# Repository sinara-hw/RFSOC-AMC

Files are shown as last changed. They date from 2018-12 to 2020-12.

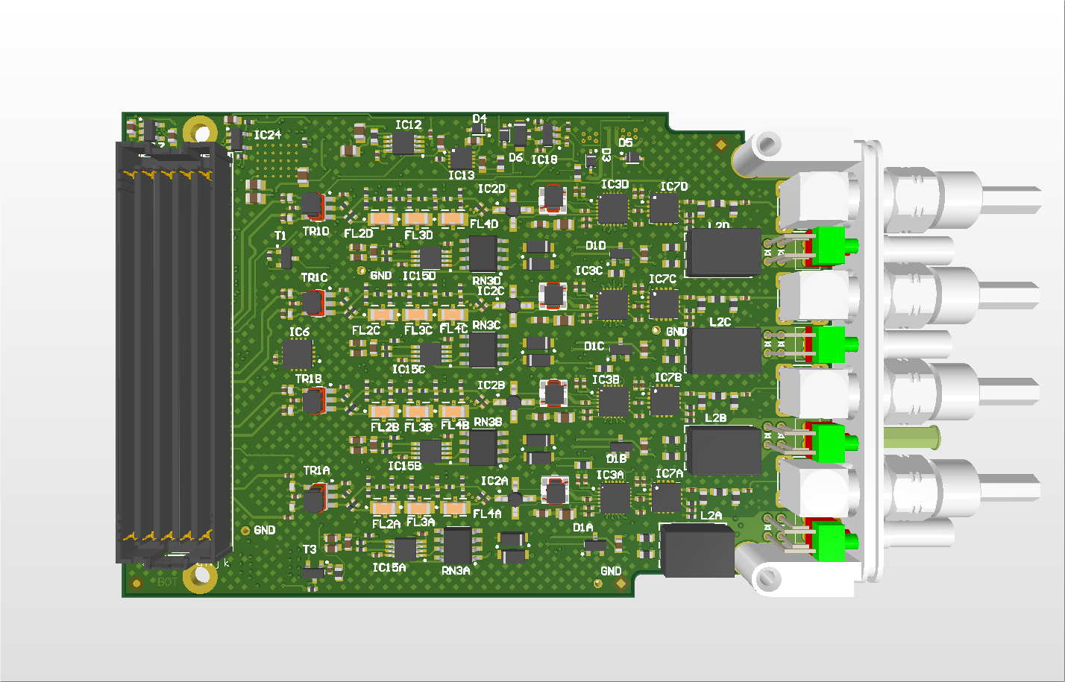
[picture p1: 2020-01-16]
DOC/mezzanine.png

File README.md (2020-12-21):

# RFSOC-AMC
AMC module with Xilinx RF-SoC and two analog front-end mezzanines for SDR and quantum applications

## Design Files

Design files (schematics, PCB layouts, BOMs) can be found at [RFSOC-AMC/Releases](https://github.com/sinara-hw/RFSOC-AMC/releases).

## Wiki

More information can be found on the [wiki](https://github.com/sinara-hw/RFSOC-AMC/wiki).

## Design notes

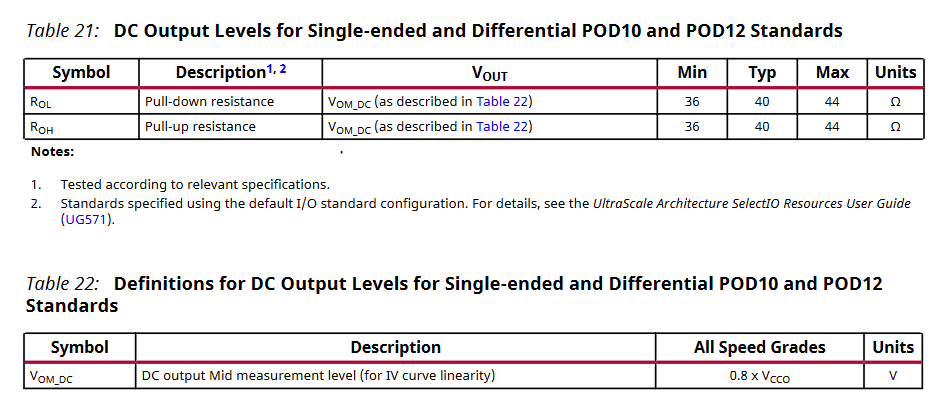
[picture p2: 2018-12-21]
POD12_o_levels.PNG

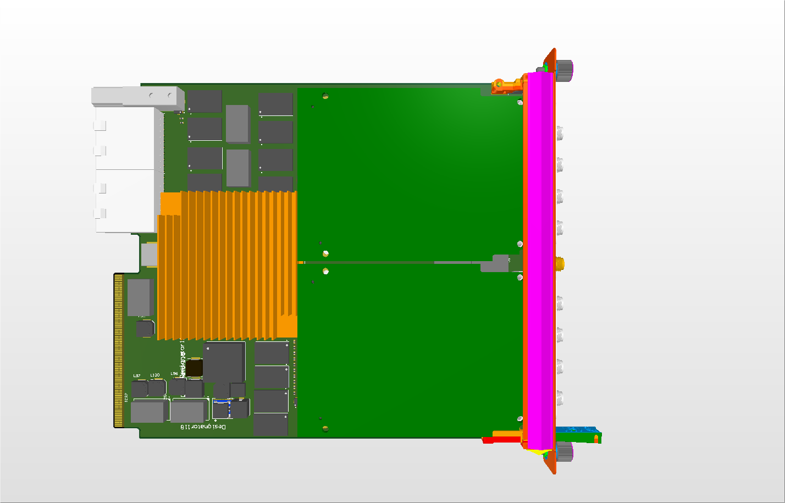
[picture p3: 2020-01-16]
DOC/top.png

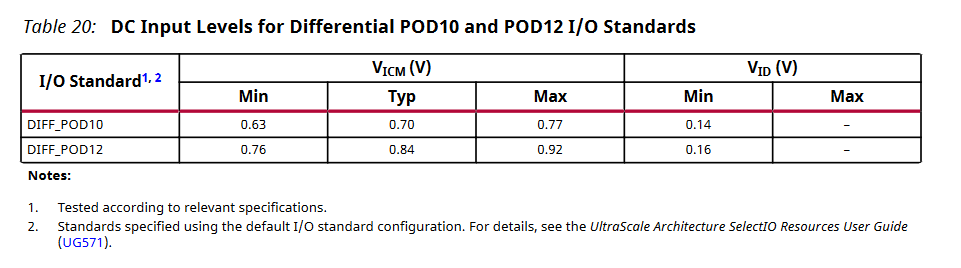
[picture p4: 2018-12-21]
POD12_i_levels.PNG

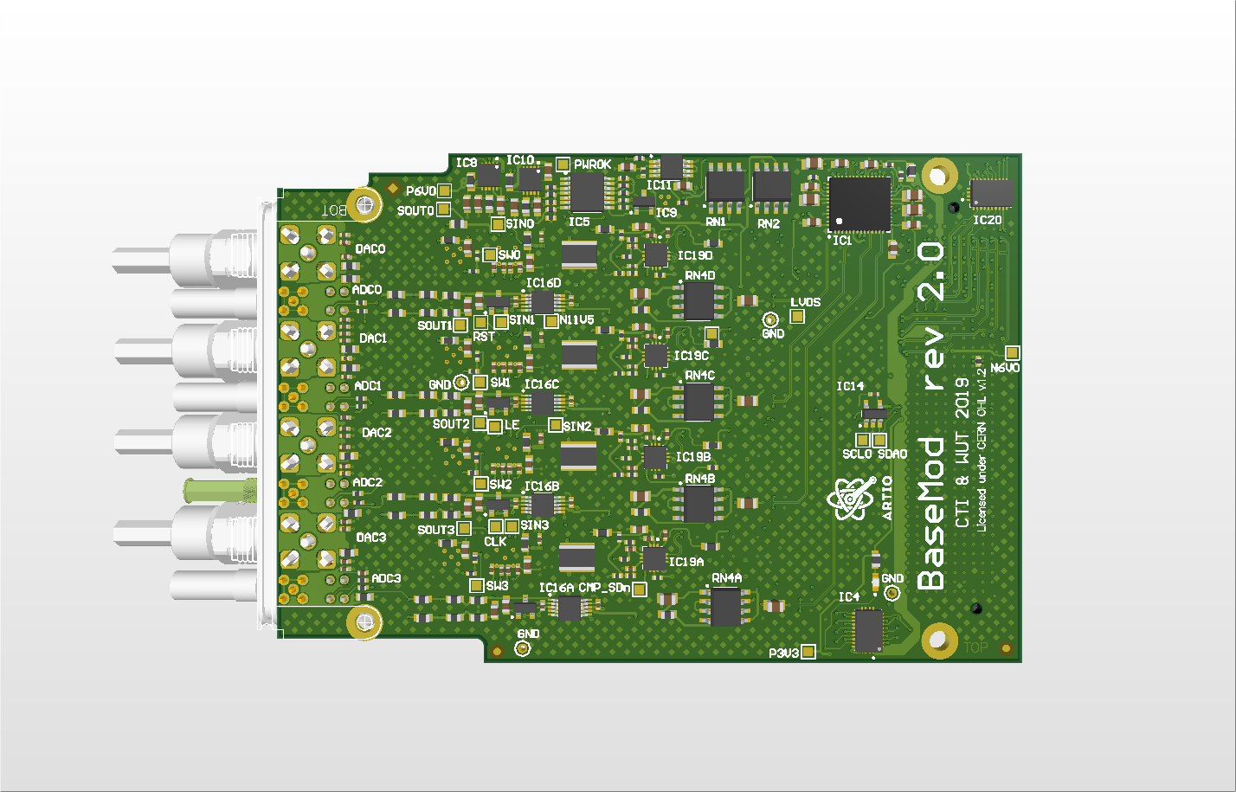
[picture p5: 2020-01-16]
DOC/mezzanine top.png

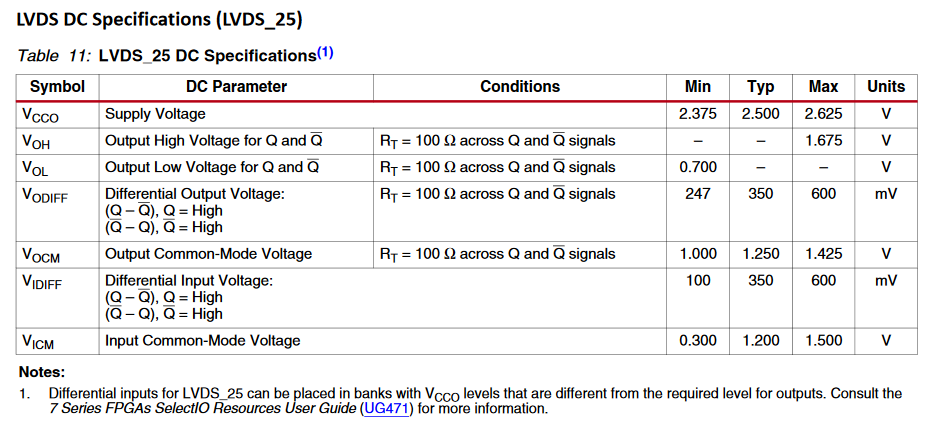
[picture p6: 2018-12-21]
LVDS_25_levels.PNG

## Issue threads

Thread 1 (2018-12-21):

[RFC] RFSoCs from Xilinx

gkasprow, 2018-12-21:
I got involved in new project at the WUT.
We will build wideband MIMO SDR. Probably on the new RFSoC that:
- are pin compatible with ZU25
- offer 8x 10G DACs and 8x 5G ADCs

You won't find any info with Mr Google. I got this news from my colleague.
For the WUT project existing 6G DAC with DUC and 4G ADC with DDC would probably be enough, but I want to play with newest SOCs.
For what applications would you use such beast? Would such upgrade for Sayma ecosystem be useful for ion trappers?
My colleagues from NBI would love to use it for superconducting qubit readout.
I still don't know what the ADC-DAC latency is. They need <1us together with demodulation and modulation algorithm. Both ADC and DAC use AXI stream.
I plan to buy ZCU111 and simply measure it.
The configuration for WUT project is minimal. I want to use 1517 package an hook up as many DDR4 channels as possible for all AWG applications.
Is there any benefit of using Sayma AMC in such configuraiton?
Initial idea is to make it as RTM and place SFP/QSFP, clock recovery, MMC, supply on AMC side.

camillehyrien, 2019-02-25:
> I saw it. But it has so many variables like inter-tile alignment and various synchronisation features.
> I will try to simulate the design with Vivado simulator where I can enter analog values and observe analog outputs.

Do you find another way to run simulation? (for example to see spectrum ? )

I have another question, do you find a way to synchronize your mesurement equipment and the ZCU111 dev board with LMK2594? Do you need to configure a MTS mode, or non-MTS mode? In which way you connected it? I tried several times but It failed.

gkasprow, 2019-02-25:
I'm still waiting for ZCU111 devkit. I didn't touch it for some time since it is a low priority.

gkasprow, 2019-09-08:
We measured the latency:
ADC - DMA - DAC. And it is roughly 160ns with interpolation and decimation and 109ns without.
Some results are [here](https://gitlab.com/wut_ise/pados/issues/8)

camillehyrien, 2019-09-09:
> We measured the latency:
> ADC - DMA - DAC. And it is roughly 160ns with interpolation and decimation and 109ns without.
> Some results are [here](https://gitlab.com/wut_ise/pados/issues/8)

Thank you for this information, I am not able to see the link : https://gitlab.com/wut_ise/pados/issues/8. May you post the result in a pdf format? Thank you

gkasprow, 2019-09-09:
This result (160 ns delay) is when using 2x interpolation and 2x decimation on DAC and ADC respectively. 4,096 GSPS.
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

109 ns is without interpolation and decimation and 4,096 GSPS, however you cannot set this configuration from GUI as GUI prevents DAC AXI stream clock from being higher than 500 MHz. I did this from PYNQ level.
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

gkasprow, 2019-09-09:
__
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

gkasprow, 2019-09-09:
The cable lengths were compensated

gkasprow, 2021-10-04:
PCB progress update
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
Mezzanine
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

dtcallcock, 2021-10-04:
FYI, there is now an open-source superconducting qubit project based on an RFSoC eval board.

[https://arxiv.org/abs/2110.00557](https://arxiv.org/abs/2110.00557)
[https://github.com/openquantumhardware/qick](https://github.com/openquantumhardware/qick)

Sandia have a similar thing aimed at ion traps too.  Not sure if that will be opened up.

[https://www.osti.gov/doecode/biblio/46631](https://www.osti.gov/doecode/biblio/46631)

gkasprow, 2021-10-04:
Yes, I know. I wrote to David already :)

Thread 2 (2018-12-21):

Design choices

gkasprow, 2018-12-21:
So far several aspects were decided:
- AMC form factor
- 2 AFE modules a'la Sayma
- RTM compatible with [RTM-SFP-QSFP](https://github.com/gkasprow/RTM_4SFP_3QSFP)
- AMC FatPipe1 support for DRTIO and PCIe
- clock racovery same as on Sayma (WR-type) + Xilinx devkit-style ADC/DAC clock generation
- 2x 64bit PL-DDR4
- 1x64bit PS-DDR4
- power supplies based on uModules like on Sayma RTM
- small FPGA for AFE control like on Sayma RTM

tprzywoz, 2019-03-18:
@gkasprow  I've just published block schematics. Please check if connections on top schematic meet the requirements.

drewrisinger, 2019-12-04:
Have there been any updates since March?

gkasprow, 2019-12-04:
Yes, the schematics are completed. We also got funding so in January we will focus on routing.

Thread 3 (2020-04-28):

AFE Connector

tprzywoz, 2020-04-28:
Will the connectors used on devkit be sufficient or do we want something with higher bandwidth?
https://www.samtec.com/products/lpaf-40-03.0-s-08-2-k-tr

gkasprow, 2020-04-28:
We can use:
-  either the same that XIlinx is using on their devkit + additional IO and LVDS lines
-  or copy solution from Sayma RTM

gkasprow, 2020-04-28:
Isn't the footprint (pitch) for both connector types compatible?

tprzywoz, 2020-04-28:
> Isn't the footprint (pitch) for both connector types compatible?

They have only different NPTH (2) and LPAF (Xilinx devkit one) has max 8 rows (not 10 like ASP on Sayma RTM). LPAF has slightly better high speed performance (based on a 3dB insertion loss) - 18.5 GHz vs 18 GHz of ASP.

tprzywoz, 2020-10-09:
After discussion with @gkasprow we are considering changing "the AFE standard" to Xilinx ZCU111 devkit one. In the current version there is copied Sayma solution:

2 x SAMTEC_ASP-134488-01 (40 x 10) connectors. Each has connections for:
- 4 x ADC and DAC channels
- 16 x FPGA IO (bank 3.3V)
- 8 x LVDS
- GT Link
- 2 x I2C
- Power rails: +/- 12V ; +/-6V ; +3V +2.5V

Potentiall new "Devkit standard":
2 x LPAF-40-030-S-08-2-K-TR (40 x 8)
**"ADC connector":**

- 8 x ADC channels (and 8 VCM)
- 20 x FPGA IO (HD bank 1.8V)
- 4 x ADCLK_IN (diff) - alternative clock source variant for each ADC CLK input
- I2C
- Power rails +3V and 1.8V

**"DAC connector":**

- 8 x DAC channels
- 20 x FPGA IO (HD bank 1.8V)
- 2 x DACCLK_IN alternative clock source variant for each DAC CLK input
- Power rails +12V, +3V, +2.5V (DAC_AVTT),+1.8V

First of all, that change will reduce the number of power rails. Currently, it makes a problem with component placement:
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

Thanks to lack of +/-12V +/- 6V power regulators and with AFE depth reduction to 76.5 mm (like FMC) we can fit all power regulators without adding extra PCB modules (as a solution to increase PCB area). Other advantages are better signal integrity (thanks to shorter traces and better isolation of analog part of PCB) and well-known connectors dedicated to RFMC (instead of FMC).

Disadvantages:

- RFSoC will accept only double width AFE boards (12V only on ''DAC connector'', I2C only on ''ADC connector")
- We won't be able to use AFE boards designed for ZCU111 devkit - the mechanical standard is too wide to fit on AMC:
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

gkasprow, 2020-10-09:
But we will be able to plug the Xilinx mezzanines to our board and our mezzanines to XIlinx devkit because connector distance would be the same. This is useful test/characterization purposes. Of course we won't be able to insert them to the AMC slot, but it's not a big issue.

gkasprow, 2020-10-09:
Moreover, we didn't characterize the Sayma connectors (FMC ones) for operation in such a high-frequency range. It's safer to stick with Xilinx devkit layout and connectors because it was already proven to work.

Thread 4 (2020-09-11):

use outside of uTCA

sbourdeauducq, 2020-09-11:
Can this card can be used in a crate composed of a bare 6U Eurorack crate plus a fan tray, in order to avoid the expense, complications, and unreliability of uTCA?

Also, would there be a solution for putting other 3U cards into the 6U crate? For instance, have a Kasli, EEM modules and some RFSoC cards in the same crate.

Do we really need a larger card and is 3U (potentially 220mm) not an option anyway? Here is a 3U RFSoC module: https://www.abaco.com/products/vp430-rfsoc-board

gkasprow, 2020-09-11:
Yes, it can be used stand-alone. There is a Molex connector for 12V and backplane adapter with SATA cables.
The idea behind MTCA was that one can reuse AFE concept from SAYMA. The RFSOC nad 8 ADC + 8 DAC channels.
The SoC is so expensive that 6-slot MTCA chassis is a small fraction of it.

gkasprow, 2020-09-11:
However, 3U in MTCA is not the same as 3U in Eurocard. There is also 6U CPCIS and Eurocard and all 6U MTCA boards could be easily updated to fit this standard because 6U CPCIS is much bigger than 6U mTCA.

gkasprow, 2020-09-11:
I have a concept of unifying both systems. We simply use CERN open [source DIOT crate](https://ohwr.org/project/diot-crate-hw/wikis/home) and make it as 6U, It uses already existing Eurocard hardware and open-source backplane. We keep the backplane,  the same supply and make the chassis 6U. Then we can use MTCA adapter.
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

sbourdeauducq, 2020-09-12:
> The idea behind MTCA was that one can reuse AFE concept from SAYMA.

How about a 3U card with the PCB centered on the front panel, and a FMC AFE on each side?

> I have a concept of unifying both systems.  We simply use CERN open source DIOT crate and make it as 6U,

This takes a lot of space.

The main advantages of RFSoC are compactness and efficiency. If we're making monster uTCA-style systems, we might as well put traditional ADCs/DACs and not deal with the often unsavory application-specific silicon designs from Xilinx.

I also worry about the reliability of all these connectors. On several occasions, Sayma has driven me mad with some new unexplained bug, which was "solved" by unplugging and replugging the RTM. The SMP connectors were another bad experience...

gkasprow, 2020-09-12:
We can try to fit the AFEs on both sides of the PCB. There will be issues with fixing holes of the connectors and mounting screws.
How would you connect these RFSOCs together?
One of the applications we build this module are SC applications. We need both PCIe/10Gb ETH fabric and DRTIO; as well as direct board-to-board low latency LVDS links. MTCA meets all of these requirements.
If we go for the EEM form-factor, we would need to make all these connections by cables.

sbourdeauducq, 2020-09-13:
Have you reviewed/measured the latency of RFSoC silicon? If it is anything like previous Xilinx designs (Zynq PS/PL AXI, transceivers, DDR controller...) you'll get hundreds of nanoseconds in various critical paths that you cannot do anything about, and those LVDS links may not do much.
Who's writing the software and gateware for these SC applications?

sbourdeauducq, 2020-09-13:
Just what I suspected.
https://forums.xilinx.com/t5/Versal-and-UltraScale/RF-SOC-ADC-latency/td-p/874365

No documentation, no characterization, things that "can't be shared", and, it would seem, a minimum of 190 sample clocks...

sbourdeauducq, 2020-09-13:
If you care about ultra low latency then you should probably use something like this:
https://www.teledyne-e2v.com/shared/content/resources/File/documents/broadband-data-converters/EV12DS480/Preliminary%20DS%2060S%20217580_EV12DS480AZP_rev%20A.pdf

Then µTCA is perhaps less inappropriate for a large PCB with those DACs and support circuitry.

gkasprow, 2020-09-13:
We measured latency. It is 120ns including DMA

gkasprow, 2020-09-13:
If you combine 8 ADCs + 8 DACs + very large FPGA then you will end up wich a much high price tag than RFSOC. These discrete ADCs and DACs consume a lot of IOs and current. The RFSOC with all ADCs and DACs (and no logic) consume much less than 10W of power.
Anyway, we got funding for the RFSOC module in MTCA form factor.

gkasprow, 2020-09-13:
We have two applications (and clients) for RFSOCs so far
- superconducting QC. Here we need both PCIe/10GE and RTIO/WR. We deliver the base platform and the client does the rest of the coding. DRTIO/WR sits in dedicated timing FPGA so the RFSOC is maintained by the client.
- massive MIMO SDR, here we need both sync and high bandwidth PCIe/10GE. We already have working GNU Radio support.
- so far we got very little interest from ion trappers. If there is interest, we can consider making more appropriate form factor.

b-bondurant, 2022-09-29:
Sorry if I'm late to the party, but in the long term I think there is interest from ion trappers. At Duke we currently have 5 experiments that I know of using the RFSoC in one form or another for gates. 3 using the ZCU-111 eval board and 2 using the Pentek 5950s.

Our current gateware is from Sandia (and therefore closed-source), and the execution model is very AWG-like -- pulse sequences have to be pre-compiled and uploaded and then the runtime component is just a TTL trigger. In terms of output, it's basically a 2-tone DDS with cubic splines for the coefficients. There are a few other gateware features like crosstalk cancellation and the ability to do feed-forward based on the repetition rate of our pulse laser via one of the ADC channels.

I say "long term" because it would be tough to convince any current experiments to move away from a working solution, but for future experiments I think better integration with ARTIQ/the coredevice would be a big selling point.

gkasprow, 2022-09-29:
@b-bondurant We are currently designing a more affordable [RFSOC in 3U](https://github.com/sinara-hw/RFSOC_SAWG/wiki) form factor that does not need an expensive MTCA environment.

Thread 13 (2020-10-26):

Missing power supply P1V8F

filipswit, 2020-10-26:

tprzywoz, 2020-11-03:
There is no P1V8F in new version.

Closed 2020-11-03.

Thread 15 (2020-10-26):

Missing decaps IC83

filipswit, 2020-10-26:
Missing decaps on all VDDO[1..9] power pins

tprzywoz, 2020-10-29:
Added + all VDDO changed to P3V3 -> it is more flexible configuration.
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

Closed 2020-11-21.

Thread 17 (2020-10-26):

Missing pullups in power good lines

filipswit, 2020-10-26:
Almost all power good signals are not equipped with required pull up resistors

tprzywoz, 2020-10-29:
Added

Closed 2020-11-21.

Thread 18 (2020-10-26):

Inconsequence naming

filipswit, 2020-10-26:
Enable and power good signals contain **AMC** in name but power bus has **AMS** in name

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

tprzywoz, 2020-10-29:
Fixed

Closed 2020-11-21.

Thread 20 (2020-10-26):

Wrong capacitor operating voltage

filipswit, 2020-10-26:
All input capacitors on IC14 are for far to low voltage, especially electrolytic for 4V!

tprzywoz, 2020-10-29:
Fixed

Closed 2020-11-21.

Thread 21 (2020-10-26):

Wrong voltage

filipswit, 2020-10-26:
Vout3 on IC12 is set to 1.8V instead of 2.5V

tprzywoz, 2020-11-03:
New voltage configuration on IC12

Closed 2020-11-03.

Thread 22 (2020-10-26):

Missing variants

filipswit, 2020-10-26:
- [ ] On all LTM4644s INTVCC supply and ground are tied together with 0R jumpers

- [ ] SDIO_DETECT R452 or R454 one of them should be mounted

tprzywoz, 2020-11-10:
Fixed variants in CDR_WR_oscillators.
LTM4644 MODE default connected to GND (INTVCC disconnected).
SDIO_DETECT default pullup.

Closed 2021-06-27.

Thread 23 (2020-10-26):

Missing decaps IC9

filipswit, 2020-10-26:
Each VCC input should be bypassed with 100nF capacitor

tprzywoz, 2020-10-29:
I just copied configuration from DevKit.

Added 4 x 100nF.

Closed 2020-11-21.

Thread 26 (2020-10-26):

Change DDR CK termination capacitor to 10nF

filipswit, 2020-10-26:
https://github.com/elhep/AFCZ/issues/68

tprzywoz, 2020-10-30:
Changed

Closed 2020-11-21.

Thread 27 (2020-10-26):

QSPI1/2 CLK is pulled low

filipswit, 2020-10-26:
Lok at: https://github.com/elhep/AFCZ/issues/80

tprzywoz, 2020-10-30:
Deleted both pull-down resistors.

Closed 2020-11-21.

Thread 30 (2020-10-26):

PS has disabled access to flash when P3V3MP is low

filipswit, 2020-10-26:
https://github.com/elhep/AFCZ/issues/78

tprzywoz, 2020-10-30:
IC57 and IC59 OE pins connected to GND

Closed 2020-11-21.

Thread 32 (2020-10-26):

Consider connecting dedicated SYSMON pins to I2C bus

filipswit, 2020-10-26:
https://github.com/elhep/AFCZ/issues/138
Dedicated pins are in bank 65: AH13 and AG12.

tprzywoz, 2020-10-30:
I think it's impossible. I have to transfer one byte of DDR4 to bank 64 where are only 8 free pins (because of a reduced number of pins in bank).

Closed 2020-11-22.

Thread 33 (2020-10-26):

USB

filipswit, 2020-10-26:
The most probably, USB is in host configuration (as in ZCU111) then:

- [ ] Vbus resistorR614 should be 10k

- [ ] C818 should be more than 120uF

tprzywoz, 2020-10-30:
I assumed that you meant 10k and I changed that.
Capacitors copied from AFCZ: 3 x 47uF.

filipswit, 2020-10-30:
Of course 10k.

Closed 2020-11-21.

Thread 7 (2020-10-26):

Pullup strength on I2C multiplexers

filipswit, 2020-10-26:
Is there any reason why there are two values, 2k2 and 10k pullups?

gkasprow, 2020-10-26:
Yes. we need low-value resistors that make sure the edges are steep. The high-value resistors make sure we have a high logic state when the port is inactive. If we use all 2k2 then logic low state will be affected.

Closed 2020-10-26.

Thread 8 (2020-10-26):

DESY recommendation class D1.4 for RTM connector

filipswit, 2020-10-26:
According to changes in AFCv4 and AFCZ please make connector compatible with D1.4 recomendation https://github.com/elhep/AFCZ/issues/29

tprzywoz, 2020-10-27:
@gkasprow I assume RTM_4SFP_3QSFP will also be compatible with D1.4.

gkasprow, 2020-10-27:
what features of RTM_4SFP_3QSFP  are not compatible with D1.4 ?

tprzywoz, 2020-10-28:
CLKA clock https://github.com/elhep/RTM_4SFP_3QSFP/issues/4

tprzywoz, 2020-10-28:
I made connector compatible with D1.4 with one exception: there is no free SRCC/MRCC IO for CC IO's, so they are connected to ''normal" Artix pins (bank 2.5V for LVDS).

Closed 2021-07-04.

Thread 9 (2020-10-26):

Swapped polarity on RTM connector

filipswit, 2020-10-26:
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

gkasprow, 2020-10-26:
LEt's call all RTM LVDS line just LVDSxx as it is now in Sayma boards

tprzywoz, 2020-10-28:
Fixed. I renamed IOs line as in AFC board.
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

Closed 2020-11-21.

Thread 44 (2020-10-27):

Power supply control and I2C mux reset during MMC reset

filipswit, 2020-10-27:
As in AFC and AFCZ, add MCP23016 for power sequecing.

tprzywoz, 2020-11-04:
Added TCA9539 like in AFCZ. I reduced enable lines to 18 to avoid second IO expander. Consequences:

- AMS_CLK_VCC3V3 LDO enable connected to VIN (P3V5).
- P2V5 / DAC_AVTT enable connected to VIN (P5V0).
- One common enable signal for DAC_AVCC / DAC_AVCCAUX / ADC_AVCC (Xilinx DS926: can be powered at any time and have no power-up sequencing requirements.)

Closed 2020-11-21.

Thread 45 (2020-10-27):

Power budget

filipswit, 2020-10-27:
Use LTpowerCAD to make power budget. With nice drawing will be easier to verify if there aren't any more mistakes.

tprzywoz, 2020-11-10:
I added to repo rfsoc.ltp3 file. I couldn't find information about RFMC power limits for Xilinx Eval but based on ZCU111:

- 2.5V (DAC_VTT) was designed for max 500mA (including SoC and RFMC)
- 1.8V (VCC1V8) was designed for max 2A. We have only additional Artix-7 and 4A current limit - should be enough.
- 3.3V it's really hard to estimate ZCU power limit for this rail. In current RFSoC_AMC design, current limit is 2,7A (all IC worst case). It can be increased to 6,7A by merging P1V13 and MGT1V2.

filipswit, 2020-11-21:
Good job!

AMC module (+eventual RTM) shouldn't draw more than 80W, now it's almost 100W.
Same with 3V3_MP, it should not exceed 150 mA

But I don't think you can do anything with it.

Closed 2021-06-27.

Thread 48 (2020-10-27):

Pinout bug in RFMC_DAC connector

filipswit, 2020-10-27:
There is 2 pin shift on signals:
RFMC_DAC_01
RFMC_DAC_02
RFMC_DAC_03
RFMC_DAC_04

tprzywoz, 2020-11-02:
Shift was on signal 01 03 05 07. Fixed.

Closed 2020-11-21.

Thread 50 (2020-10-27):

RTM I2C Bus Isolation an Pull-Ups

filipswit, 2020-10-27:
According to mTCA 4.1 specification RTM I2C bus should be separated by bidirectional buffer powered from P3V3_MP (REQ 3-7).

RTM I2C pull-ups should be present only on RTM module, according to Figure 3-1.

https://github.com/elhep/AFCZ/issues/20

tprzywoz, 2020-11-02:
Copied AFCZ solution.

Closed 2020-11-21.

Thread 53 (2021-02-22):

Components availability

kaolpr, 2021-02-22:
After reviewing BOM at we have the following remarks:

* LPC1776FET180,551 has limited availability (not stocked by major distributors) - this will be a problem for prototype series, if keeping the same package maybe LPC1788FET180,551 could be an alternative?
* VX-501-0251-122M88 has 18 week lead time, I hope this **will be** a problem :P, can we have some alternative here?
* XC7A35T-3CSG325E is not available on stock, can we use XC7A50T-3CSG325E? @sbourdeauducq - I assume that speed grade 3 is required?

sbourdeauducq, 2021-02-23:
Yes, SG3 is better generally.

sbourdeauducq, 2021-02-23:
And 7A35T and 7A50T have the same die inside, so it'll work regardless of what Xilinx thinks :)

tprzywoz, 2021-02-24:
We can use CVHD-950-122.880 instead of VX-501-0251-122M88.

filipswit, 2021-05-16:
Heatsink **AAVID** **342947** looks unavailable.

I suggest to use same as on AFCZ: **SKV585811-CU**

tprzywoz, 2021-06-10:
Heatsink changed to SKV585811-CU

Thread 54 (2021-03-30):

Schematic changes

tprzywoz, 2021-03-30:
Changes made after the first schematic review:

- Artix banks 34 <-> 15 were swapped.
- IC71 (USB Transceiver) REFSEL pins connected to ULPI_VDDIO (not direct to P1V8).
- added 10k pullup to RGMII1_RX_CLK (like in AFCZ)
- DDR_VTT_PGOOD (common for 3 DDR termination IC) had 3 pullups - 2 removed
- MII1_MDIO had 2 pullups - 1 removed
- Micro USB B changed to USB C (like in AFCZ)
- U1 (VX-501-0251-122M88) changed to OSC1 (CRYSTEK_CVHD-950-122.880)
- New regulator for P5V0 - with internal inductor
- External CLK connector (J15) changed to U.FL.
- MMC push-button removed from the front panel (right angle changed to straight)
- Fixed some polarity issues
- Fixed RTM connector issue - swapped component part B and C

tprzywoz, 2021-07-02:
RC2
Fixed GT RFSoC - Artix connection (swapped TX RX at harness entry)
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

tprzywoz, 2021-07-16:
RC3:
Removed B17 - one of middle screw holes for mounting the RFMC
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

Added R1001

microSD Card Connector changed to MOLEX_502570-0893 (front panel issue with old one)

Added R456 (because of issue with IC39 on AFCv4)

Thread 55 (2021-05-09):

L2 L25 ferrite beads current rating

filipswit, 2021-05-09:
Current flow is over component current rating (2x2A), while estimated current is 5,3A.

tprzywoz, 2021-05-10:
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

5,3A is current of P1V2 + MGTAVTTF. MGTAVTTF estimated current is 0,4A

filipswit, 2021-05-10:
ok, sorry.

Closed 2021-05-10.

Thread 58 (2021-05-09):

Missing variant

filipswit, 2021-05-09:
R397or R399 should be mounted
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

Closed 2021-06-27.

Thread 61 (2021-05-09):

Missing pull-ups

filipswit, 2021-05-09:
ARTIX_CFG_
- PROG_B
- INIT_B

should have an external ≤ 4.7 kΩ pull-up resistors to VCCO_0.

tprzywoz, 2021-05-11:
Added 4.7 kΩ pull-up resistors
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

Closed 2021-06-27.

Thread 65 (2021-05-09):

Lack of recommended capacitors

filipswit, 2021-05-09:
On Artix power supply rails, Xilinx recommends some additional capacitors, so it would be good to add:

- VCCINT
100uF

- VCCBRAMF
47uF

- VCCAUXF
47uF and 2x4.7uF

- Each VCCO_x
47uF and 4.7uF

- Each MGT supply
4.7uF

tprzywoz, 2021-06-28:
The design was copied from Sayma_RTM so it should work. But I added all recommended capacitors except 47uF for VCCOx.

Closed 2021-07-04.

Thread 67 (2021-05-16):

schematic details

filipswit, 2021-05-16:
- [ ] missing logo
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

- [ ] table not updated
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

- [ ] out of sheet object
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

tprzywoz, 2021-05-17:
Done

filipswit, 2021-05-22:
- [ ] missing file
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

filipswit, 2021-05-29:
- [ ]  Missing files on sheet SoC_FPGA_64_65_66_DDR4.SchDoc
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

Closed 2021-07-04.

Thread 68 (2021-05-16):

IC78 missing pullup

filipswit, 2021-05-16:
Reset input should be connected to VCC through a pull-up resistor

tprzywoz, 2021-05-17:
Added 10k pull-up

Closed 2021-06-27.

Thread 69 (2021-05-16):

multiple net names

filipswit, 2021-05-16:
Is there any reason why there are multiple net names?
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

It's the same with: DAC_AVCCAUX, ADC_AVCC, MGRTAVCC

tprzywoz, 2021-05-17:
Deleted redundant "BUS" names. Should be removed together with current sense resistors which were between power net and _bus net.

Closed 2021-06-27.

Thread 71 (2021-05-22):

missing front panel mounting holes

filipswit, 2021-05-22:

tprzywoz, 2021-05-25:
Added:
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

Closed 2021-06-27.

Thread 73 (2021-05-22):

Unconnected via

filipswit, 2021-05-22:
- [ ]  close to IC36 via is not connected to power plane, move plane border to connect it
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

- [ ] C651
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

tprzywoz, 2021-05-24:
Fixed

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

Closed 2021-06-27.

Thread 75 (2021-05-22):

IC13 - layout considerations

filipswit, 2021-05-22:
-  This GND vias don't help with current flow from SMPS. You can move them and have polygon without holes.

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

-  connect 1st pad of C948 directly to GND plane
- C953, remove this
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

tprzywoz, 2021-05-26:
1. Deleted P12V0 via - added polygon on BTM layer instead. GND via moved.
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

2. Done
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

3. Removed

Closed 2021-06-27.

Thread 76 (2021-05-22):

IC79 - layout considerations

filipswit, 2021-05-22:
- You can try to move C988 to the right and save some copper for polygon
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

- Did you simulate this supply? 16A looks like quite a lot. What do you think about moving this edge up to have some more copper?
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

tprzywoz, 2021-06-28:
1.
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

2. Power planes were redesigned. Current VCCINT_IO_BRAM_PS_SDFEC plane:
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

Closed 2021-07-04.

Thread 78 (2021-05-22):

tie polygon P2V5

filipswit, 2021-05-22:
Tie polygon P2V5 on L16 with more vias, now it's tied with one via. Turn on "remove dead copper" on it, there is floating part.

tprzywoz, 2021-05-28:
Removed dead copper, added 4 vias:
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

Closed 2021-06-27.

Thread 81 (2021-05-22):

IC10 - decaps

filipswit, 2021-05-22:
Pin 15 doesn't have decoupling capacitor close to it.

tprzywoz, 2021-06-08:
Moved C172:
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

Closed 2021-06-27.

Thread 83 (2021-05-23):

components to close to each other

filipswit, 2021-05-23:
- [ ] IC63 is to close to C936
- [ ] This selector will be hard to change with mounted radiator
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

filipswit, 2021-05-29:
- [ ] C373 C372, can be moved to the left, to wouldn't overlap of IC23 courtyard
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

filipswit, 2021-05-29:
- [ ] This selector will be hard to change with mounted radiator

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

tprzywoz, 2021-06-08:
All done. The first selector moved to BTM:
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

Closed 2021-06-27.

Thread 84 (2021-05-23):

General RAM issue

filipswit, 2021-05-23:
Mostly one byte is routed on few layers. It should be on one.

UG583:
``DQ and DQS signals in the same byte group should be routed in the same layer from
UltraScale device to DRAM/DIMM, except in the breakout areas. Include the data mask
(DM) in the byte group as applicable.``

tprzywoz, 2021-06-28:
As current design has passed all RAM simulation tests, I think that it's not worth changing the layout.

filipswit, 2021-07-04:
In general I dislike it. But since Altium count delays and simulation passes it may be right.

Closed 2021-07-04.

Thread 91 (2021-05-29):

overlay

filipswit, 2021-05-29:
- [ ] Overlapping designator
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

- [ ] Add description to DAC_AVCC test point
- [ ] Add description to FPGA_I2C test point
- [ ] Add description to MMC_I2C test point
- [ ] Add description to headers: JTAG, I2C, Ethernet
- [ ] Add board description
- [ ] rotate label L33
- [ ] rotate label IC35
- [ ] J3 label out of the board

tprzywoz, 2021-05-31:
Done. Added description for both RFSoC and Artix I2C.

tprzywoz, 2021-05-31:
Added variants description:
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

Closed 2021-06-27.

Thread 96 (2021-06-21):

RFSOC-AMC PI verification

tprzywoz, 2021-06-21:
ADC_AVCC: 1,6 A
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

tprzywoz, 2021-06-21:
P1V8 (ADC_AVCCAUX, VCC_PSDDR_PLL, SYSMON_AVCC, VCCAUXF)
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

tprzywoz, 2021-06-21:
AMS_CLK_VCC3V3
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

tprzywoz, 2021-06-21:
DAC_AVCC - 1,3 A
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

tprzywoz, 2021-06-21:
DAC_AVCCAUX
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

tprzywoz, 2021-06-21:
P2V5 (DAC_AVTT):
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

tprzywoz, 2021-06-21:
MGT1V2 (MGTAVTT 4 A, VCC_PSPLL 100 mA)
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

tprzywoz, 2021-06-21:
MGT1V8
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

tprzywoz, 2021-06-21:
MGTAVCC (1,8 A)
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

tprzywoz, 2021-06-21:
P1V0 (Artix VCCINT MGTAVCC VCCBRAM - all 1,22 A)
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

tprzywoz, 2021-06-21:
P1V2 (MGTAVTTF)
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

tprzywoz, 2021-06-21:
MGTRAVCC
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

tprzywoz, 2021-06-21:
P12V0
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

tprzywoz, 2021-06-21:
P1V13
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

tprzywoz, 2021-06-21:
P3V3:
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

tprzywoz, 2021-06-21:
P3V5:
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

tprzywoz, 2021-06-21:
P5V0
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

tprzywoz, 2021-06-21:
PAYLOAD_PWR
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

Current Density Layer 1:
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

tprzywoz, 2021-06-21:
VCCINT (30 A)
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

tprzywoz, 2021-06-21:
VCCINT_AMS (7A)
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

tprzywoz, 2021-06-21:
VCCINT_IO_BRAM_PS_SDFEC (13 A)
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

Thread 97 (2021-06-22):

RFSOC-AMC SI verification

tprzywoz, 2021-06-22:
PL0   DDR4_2666

Data Write
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

Data Read
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

Address
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

Differential Nets
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

CLK-DQS Skew
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

tprzywoz, 2021-06-22:
PL1 DDR4_2666

Data Write
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

Data Read
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

Address
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

Differential Nets
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

CLK-DQS Skew
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

kaolpr, 2022-01-26:
@tprzywoz Have you done simulations for MGT lines?

tprzywoz, 2022-01-27:
Yes, to AMC edge connector with full speed, to RTM connector 12 Gb/s.

gkasprow, 2022-01-27:
Is there a chance that this board could work at 28Gbit/s over RTM ? We can use a higher grade RTM connector.

tprzywoz, 2022-02-02:
Eye diagrams are fine for 25Gbit/s. At 28 Gbit/s there are problems with the last Quad which has mounting options and more vias.

gkasprow, 2022-02-02:
I assume this is without the RTM board.
Anyway, there is an idea to use Samtec Flyover to QSFP cable. From one side we exit close to MGT, from the other side we have a QSFP28 connector. We only need to find a place for Flyover connector, but it is tiny,
We could implement it in new revision,

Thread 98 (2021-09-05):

I2C multiplexers addresses

filipswit, 2021-09-05:
Just keep in mind that since IC3 MUX(addr: 0x70) is used on mezzanine, the default address of IC30 can't be the same.

tprzywoz, 2021-09-13:
Added big red note about this near I2C device address map.

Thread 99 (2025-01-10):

status of ARTIQ port to an RFSoC

jbqubit, 2025-01-10:
The thesis by Brad Bondurant (2024) discusses work toward a port of ARTIQ to the ZCU111. From conversations with Brad and, now, reading his thesis I surmise that he got slowed down by porting the Xilinx-provided C libraries to rust. Definitely the right long-term approach but pretty hard as Xilinx code is notoriously brittle. To my eye it looks like he made great progress and the narrative accompanying his code (in the thesis CH 5) is quite helpful.

https://dukespace.lib.duke.edu/items/6d3950ae-a4ea-4caf-bc8e-2e491eeddbc3

The source is here.

https://gitlab.com/duke-artiq/zynqmp-rs

As far as I know a functional ARTIQ port to an RFSoC remains nascent. I hear Warsaw (@gkasprow) is also working on a port. I gather M-Labs supported parts of Brad's port (@sbourdeauducq). Anybody know the status of these efforts? Are any of the efforts inclusive of the ZU48DR used in the AMD RFSoC 4x2?

gkasprow, 2025-01-11:
@kaolpr

kaolpr, 2025-01-11:
We have one person working on the subject based on work by Brad. He's in contact with Brad and currently we assume the approach as in case of Zynq7000.

However, I'm curious what were the arguments against  Linux based approach (ARTIQ app on Linux + RT cores). That could prevent us from reverse engineering Xilinx codes.

pjedyk, 2025-03-14:
I have started working on a Zynq UltraScale+ port - specifically for Genesys ZU-5EV, but it should be easily portable to any ZCU.

Currently, I can share a suggestion for a development environment.

https://github.com/pjedyk/artiq-new/tree/wip/boards/genesys_zu-5ev

The firmware part will be stacked Rust on C, so the regular Xilinx/AMD C runtime jumps into Rust after initialising all the CPU and C runtimes.

The gateware part is in Migen. I have written experimental Migen-Vivado integration that generates a Platform class based on the Vivado project.

The environment is designed to keep costly reverse engineering to a minimum. It includes formatting/linting facilities for Python.

I plan to use AMP (maybe with OpenMP integration?). I consider some OS-es (FreeRTOS?) that could use MPU/MMU. I also plan some experiments with FreeRTOS SMP; however, that probably won't be the case.

I also plan to distribute tasks between Cortex-R and Cortex-A cores.

kaolpr, 2025-03-15:
@sbourdeauducq What are your experiences with Not OS used for Nix Servo? Do you think this would be applicable here (boldly assuming  that we accept the use of Linux)?

pjedyk, 2025-04-11:
I have successfully done several experiments with Linux and Zynq US+ on Genesys ZU-5EV and confirm that it is possible and has great potential to use the following architecture:

- Low-level firmware in split-mode AMP on two Cortex-R cores, talks with PL via AXI, with Cortex-A53s via OpenAMP. Written mostly in Rust, compiled to static *.a using cargo. Glue layer in C, compiled using Vitis and linked with Rust's *.a. C Layer provides OpenAMP and Xil HAL without the need to rewrite them (extern "C" in Rust).
- Middle-level firmware as Linux on four Cortex-A53 cores, talks with Cortex-Rs via OpenAMP, PL via AXI, and the rest of the world via Ethernet and UART. We will use Yocto/OE with meta-xilinx, so no petalinux tooling is needed. I will manage not to put any bloatware to avoid annoying the neurotic guys (as I am) - OE with a custom image recipe will help.
- PL side, talks with PSU via AXI and controls physical inputs/outputs.

**I need an answer about what approach you feel more comfortable with (taking into account the design of the future custom PCBs):**

**Approach 1**: Linux boots with a RAM-stored read-write but volatile filesystem. After reboot, you lose all changes to the filesystem. However, you may mount and use non-volatile additional storage (SD cards, USB, etc.). There will also be a small, non-volatile partition for configuration (hostname, net config, etc.). You will never "brick" the device by accident unless you are very talented. You have a well-known state of a device after each reboot.

**Approach 2**: The device boots entirely from storage like an SD card or eMMC. Thus, you have a regular computer and may see previous users' trash files and get upset. You may easily break something (sudo dd, which means "destroy disk"), but you have an unlimited environment.

What are your thoughts?

If no preference, I would choose approach 1.

pjedyk, 2025-04-11:
For me, Linux is not a must. However:

- We have four Cortex-A53 cores with Mali-400 which will run Linux smoothly and additional two Cortex-R5F cores that can do the low-level job. The Zynq SoC is designed this way - it is "by the book" approach.
- Linux provides easy-to-use and understand by everyone: network interfaces configuration and management, Bash console over UART and SSH, network services like mDNS (discovering by hostname.local), ...; it adds value in the case (IMO, of course).
- Well-tuned Yocto/OE build should be much more stable than writing everything that in bare-metal, and much, much faster in development (also includes future ports to different devices).

I believe that once the new approach development environment is stable, the speed of the further development will rocket-out bare-metal grinding. I do not have a prove for that, tough.

Please consider the noteworthy fact that it is not "moving ARITQ to Linux" completely. It is delegating some well-done in Linux functions away from bare-metal, but still keeping the "main", or "novel", code in Rust on 32-bit Cortex-R5. Thus, this shall be named rather functional "balancing" to provide an optimised allocation.

Any comments are welcome; please provide as much point-of-views as possible to increase the chance of good decision.

kaolpr, 2025-04-11:
I think what @pjedyk had in mind here was stability of development.

I agree with arguments for Linux + IMO Linux as a management OS will make getting new developers a bit easier (although still not easy). It is hard to persuade someone to dedicate his time to work on the solution that is unique to a relatively narrow field. Even if this solution is technically impressive.

pjedyk, 2025-04-11:
> I think the kernels should be run on the main cores if possible.

It is possible, however, that my strategy was to first balance Linux on A53 and Rust on R5, and if this is not enough, I will put Rust on two A53s (for example).

We may run Linux only on two A53s and keep the other two for Rust (low-level) using standard Xilinx tooling - no need for reversing anything, just a different configuration.

> Is ARTIQ on Zynq unstable due to driver bugs?

The artiq-zynq repo supports Zynq 7000, not UltraScale+, afaik.

Zynq 7000 port is not trivial (delicately said) to port to Zynq US+.

I suggest an approach that radically simplifies the development. Future programmers should focus on ARTIQ functionality, not reversing HAL, rewriting bootloaders, initialising C runtime, and writing drivers for standard hardware like Ethernet.

---

Please provide information if keeping a closed ecosystem is a strict policy. If not, I recommend trying the proposed architecture and let the community test it.

I agree that "Quantity != quality", but, as I said, well-tuned (it is a keyword: **well-tuned**) Vivado+Migen+Rust+Vitis+Yocto/OE workflow shall be more on the quality side.

gkasprow, 2025-04-11:
@sbourdeauducq, we have only one man working on it and minimal financial resources. Let's make a minimal viable prototype approach first.

pjedyk, 2025-04-11:
This thread started to have traits of a political debate, not an argument-driven technical discussion.

The comment "Try writing a bare metal ... that writes something to the UART ... you'll see it's not that hard" implicitly declares that I have never used registers to handle the hardware, which is incorrect.

Another thing is that even if handling UART is not that hard, handling GPIOs is not that hard, and doing many other things is not that hard... doing it all together may be hard. It is the fallacy of composition.

I expected to:
- gather arguments for Linux
- gather arguments for bare-metal
- discuss and compare
- make decision
- implement

I can write the firmware entirely in Rust from scratch (with interrupt vectors and low-level init). I was writing custom PendSV interrupt handlers on 32-bit ARMs in assembler to switch contexts. I even used MPU on STM32 before FreeRTOS officially added it to its upstream. BUT, every time I had a serious reason to do things that way - I have never done it for "a challenge".

I wanted to use Linux to:

- Take advantage of several drivers and subsystems, particularly storage devices, filesystems, and networking.
- Improve the development and maintenance by implementing some functions (that do not require real-time awareness) under Linux using languages like Python.
- Improve setup from the user's point of view, introduce log gatherings, and store experiment results on storage devices.
- Reduce the effort of porting to future custom PCBs with Zynq US+.

Functions that should be deterministic and real-time aware are still bare metal and PL-side, so we are not resigning from anything.

I am entirely open to solid arguments.

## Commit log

2018-12-21 work in progress - initial schematic version
    [ADC_DAC_Supply.SchDoc, ADC_PLL.SchDoc, AMC_Connector.SchDoc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]
2019-03-18 Block schematics
    [ADC_DAC_Supply.SchDoc, ADC_PLL.SchDoc, AMC_Connector.SchDoc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]
2020-01-16 added imgs, sch cleanup
    [ADC_DAC_Supply.SchDoc, ADC_PLL.SchDoc, AMC_Connector.SchDoc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]
2020-11-02 New power management
    [ADC_DAC_Supply.SchDoc, AMS_CLOCK.SchDoc, CPU_LPC1776_1.SchDoc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]
2021-03-16 Initial PCB routing done
    [ADC_DAC_Supply.SchDoc, ADC_PLL.SchDoc, AMC_Connector.SchDoc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]
2021-08-17 new front panel
    [RFSoC-AMC.PrjPCB]
